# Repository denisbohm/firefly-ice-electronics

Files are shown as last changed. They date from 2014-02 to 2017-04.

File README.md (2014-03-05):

firefly-ice-electronics
=======================

Firefly Ice Activity Monitor / Internet of Things Electronics

See http://fireflydesign.com for information on the open source Firefly Activity Monitor.

Copyright and License 
---------------------
Copyright 2013-2014 Firefly Design LLC / Denis Bohm

<br />This work is licensed under a <a rel="license" href="http://creativecommons.org/licenses/by/3.0/deed.en_US">Creative Commons Attribution 3.0 Unported License</a>.

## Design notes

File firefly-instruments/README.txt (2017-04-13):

Contact: Denis Bohm
denis@fireflydesign.com
(650) 814-1714

April 13h, 2017
Customer: Firefly Design, LLC
Board: Firefly Instrument Tray rev 0.5
Number of Layers: 2
Dimensions: 193 mm x 100 mm
PCB Thickness: 1.60 mm
ENIG
RoHS Compliant
Lead Free Processing

Files

firefly-instrument-tray.sch - Eagle 7 schematic file
firefly-instrument-tray.brd - Eagle 7 board file

firefly-instrument-tray-bom.xlsx - bill of materials
firefly-instrument-tray-schematic.pdf - schematic
firefly-instrument-tray-top-diagram.pdf - top (component) side assembly diagram
firefly-instrument-tray-centroid.csv - surface mount centroid placement data

Gerbers
firefly-instrument-tray.top - top (component) side
firefly-instrument-tray.bot - bottom side

firefly-instrument-tray.slk - top (component) side silk
firefly-instrument-tray.smt - top (component) side solder mask
firefly-instrument-tray.tsp - top (component) side stencil

firefly-instrument-tray.bsk - bottom side silk
firefly-instrument-tray.smb - bottom side solder mask
firefly-instrument-tray.bsp - bottom side stencil

firefly-instrument-tray.oln - outline

firefly-instrument-tray.drd - Excellon drill
firefly-instrument-tray.dri - tool list

Notes:
1) The design is done with Eagle 7.7.0 (files are of type sch, brd, and lib)..
2) Use Firefly Design BOM tool to generate the BOM from the schematic.
3) The tDocu & Document layers show all reference designators and orientation for assembly of the top side.
4) The bDocu shows all reference designators and orientation for assembly of the bottom side.
5) DRC rules and CAM setup are from Sunstone Circuits.  For CAM setup use _tsilk for top side silk and _bsilk for bottom side silk.
6) Centroid file generator is from Screaming Circuits.

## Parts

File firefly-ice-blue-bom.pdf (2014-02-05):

Item # Qty Ref Des | Manufacturer | Mfg Part # | Distributor | Description | Package | Type | DNS | NS
1 | 1 A1 | Fractus | FR05_S1_N_0_110 | RichardsonRFPD | FR05_S1_N_0_110 smt | FALSE FALSE
2 17 C1-2 C9 C12-13 C16-17 C23 C26-31 C41 C43 C55 Murata | GRM033R60J104KE19D | Digikey | 100nF | C0201 | fine pitch FALSE FALSE
3 12 C3 C8 C10-11 C14 C20-21 C24 C36 C42 C50 C52 TDK Corporation | C0603X5R0J105M030BC | Digikey | 1uF | C0201 | fine pitch FALSE FALSE
4 | 3 C4-5 C15 | TDK Corporation | C1005X5R0J475M050BC | Digikey | 4.7uF | C0402 | smt | FALSE FALSE
5 | 2 C6 C46 | TDK | C0603C0G1E1R2B030BF | Digikey | 1.2pF | C0201 | fine pitch FALSE FALSE
6 | 2 C18 C25 | Samsung Electro-Mechanics America, Inc CL05A106MP5NUNC | Digikey | 10uF | C0402 | smt | FALSE FALSE
7 | 1 C19 | TDK Corporation | C1608X5R0J226M080AC | Digikey | 22uF | C0603 | smt | FALSE FALSE
8 | 2 C22 C48 | Johanson Technology Inc | 250R05L180GV4T | Digikey | 18pF | C0201 | fine pitch FALSE FALSE
9 | 2 C32-33 | AVX Corporation | 02013A220GAT2A | Digikey | 22pF | C0201 | fine pitch FALSE FALSE
10 | 2 C34-35 | Johanson Technology Inc | 250R05L150GV4T | Digikey | 15pF | C0201 | fine pitch FALSE FALSE
11 | 1 C39 | Murata | C0603X7R1E102K030BA | Digikey | 1nF | C0201 | fine pitch FALSE FALSE
12 | 1 C40 | Murata | GRM033R60J333KE01D | Digikey | 33nF | C0201 | fine pitch FALSE FALSE
13 | 1 C44 | TDK | C0603X5R1E222K030BA | Digikey | 2.2nF | C0201 | fine pitch FALSE FALSE
14 | 1 C47 | TDK | C0603C0G1E1R8C030BF | Digikey | 1.8pF | C0201 | fine pitch FALSE FALSE
15 | 1 C51 | Kemet | C1206C107M9PACTU | Digikey | 100uF | C1206 | smt | FALSE FALSE
16 | 2 C53-54 | TDK Corporation | C0603X5R0J474M030BC | Digikey | 470nF | C0201 | fine pitch FALSE FALSE
17 | 2 D0 D4 | Rohm Semiconductor | SML-P11UTT86 | Digikey | LEDD0402 | D0402 | smt | FALSE FALSE
18 | 3 D1-3 | Rohm Semiconductor | SMLP36RGB2W3 | Digikey | SMLP36 | smt | FALSE FALSE
19 | 1 D5 | Panasonic Electronic Components | LNJ847W83RA | Digikey | LEDD0402 | D0402 | smt | FALSE FALSE
20 | 1 D6 | Panasonic Electronic Components | LNJ347W83RA | Digikey | LEDD0402 | D0402 | smt | FALSE FALSE
21 | 1 D10 | Rohm Semiconductor | RB161M-20TR | Digikey | BAT54WSSOD-123F | SOD-123F | smt | FALSE FALSE
22 | 1 J1 | Hirose Electric Co Ltd | ZX62WD1-B-5PC | Digikey | USB-5PINZX62WD1-B-5PC ZX62WD1-B-5PC | smt | FALSE FALSE
23 | 1 J2 | Harwin Inc | M40-3100345R | Digikey | CON-6SOCKET | M40-3100345R | smt | FALSE FALSE
24 | 1 L1 | TDK | MLG0603P8N2J | Digikey | 8.2nH | L0201 | fine pitch FALSE FALSE
25 | 1 L2 | TDK | MLG0603P5N6S | Digikey | 5.6nH | L0201 | fine pitch FALSE FALSE
26 | 1 L3 | TDK | MLG0603S3N9S | Digikey | 3.9nH | L0201 | fine pitch FALSE FALSE
27 | 2 L4 L9 | TDK Corporation | MPZ0603S220C | Digikey | Ferrite Bead | L0201 | fine pitch FALSE FALSE
28 | 1 L6 | Taiyo Yuden | HKQ0603S7N5H-T | Digikey | 7.5nH | L0201 | fine pitch FALSE FALSE
29 | 1 L7 | WURTH | 74479775210 | Digikey | 1uH | L0805 | smt | FALSE FALSE
30 | 2 R1 R9 | Panasonic Electronic Components | ERJ-1GEF4701C | Digikey | 4.7k | R0201 | smt | FALSE FALSE
31 | 6 R2 R7 R15 R31-33 | Yageo | RC0201FR-07100KL | Digikey | 100k | R0201 | smt | FALSE FALSE
32 | 1 R3 | Panasonic Electronic Components | ERJ-1GEF1503C | Digikey | 152.4k | R0201 | smt | FALSE FALSE
33 | 1 R4 | Panasonic Electronic Components | ERJ-1GEJ105C | Digikey | 1M | R0201 | smt | FALSE FALSE
34 | 2 R5 R14 | Panasonic Electronic Components | ERJ-1GE0R00C | Digikey | 0 (OPT) (do not stuff) | R0201 | smt | TRUE | FALSE
35 | 1 R6 | Panasonic Electronic Components | ERJ-1GEF24R9C | Digikey | 25 | R0201 | smt | FALSE FALSE
36 | 1 R8 | Panasonic Electronic Components | ERJ-1GEF1242C | Digikey | 12.4k | R0201 | smt | FALSE FALSE
37 | 1 R10 | Panasonic Electronic Components | ERJ-1GEF3922C | Digikey | 39.2k | R0201 | smt | FALSE FALSE
38 | 1 R11 | Panasonic | ERJ-1GEF2202C | Digikey | 22k | R0201 | smt | FALSE FALSE
39 | 1 R12 | Yageo | RC0201FR-07100KL | Digikey | 100k (do not stuff) | R0201 | smt | TRUE | FALSE
40 | 3 R17 R20 R23 | Panasonic Electronic Components | ERJ-1GEF51R0C | Digikey | 50 | R0201 | smt | FALSE FALSE
41 | 1 R25 | Panasonic Electronic Components | ERJ-1GE0R00C | Digikey | 0 | R0201 | smt | FALSE FALSE
42 | 2 R27-28 | Panasonic Electronic Components | ERJ-1GEF15R0C | Digikey | 15 | R0201 | smt | FALSE FALSE
43 | 1 U1 | Energy Micro | EFM32LG330F256 | Digikey | QFN64 | fine pitch FALSE FALSE
44 | 1 U2 | Nordic Semiconductor | nRF8001-R2Q32-T | Mouser | QFN-32 | fine pitch FALSE FALSE
45 | 1 U3 | ST | LIS3DHTR | Digikey | LGA16_3X3 | fine pitch FALSE FALSE
46 | 1 U4 | Freescale Semiconductor | MAG3110FCR1 | Digikey | DFN10-2X2 | fine pitch FALSE FALSE
47 | 1 U5 | Texas Instruments | LP5523TMX/NOPB | Digikey | WL-CSP-25 | fine pitch FALSE FALSE
48 | 1 U6 | Diodes Inc | DMC2990UDJ-7 | Digikey | SOT963 | fine pitch FALSE FALSE
49 | 1 U7 | Microchip | MCP73832-2ACI/MC | Mouser | DFN8 | fine pitch FALSE FALSE
50 | 1 U8 | NXP Semiconductors | IP4059CX5/LF,135 | Digikey | WLCSP5 | fine pitch FALSE FALSE
51 | 1 U9 | Fairchild Semiconductor | FPF1005 | Digikey | MICROFET-2X2-6L smt | FALSE FALSE
52 | 1 U10 | STMicroelectronics | STM6519AHARUB6F | Digikey | UDFN6 | fine pitch FALSE FALSE
53 | 1 U11 | Texas Instruments | TPS78222DRVR | Digikey | S-PWSON-N6 | smt | FALSE FALSE
54 | 1 U12 | Texas Instruments | TPS62080ADSGT | Mouser | S-PWSON-N8 | fine pitch FALSE FALSE
55 | 1 U13 | NXP Semiconductor | NX3L1T53GM,125 | Digikey | SOT902-2 | fine pitch FALSE FALSE
56 | 1 U14 | Fairchild Semiconductor | FDFMA2P857 | Digikey | (do not stuff) | MO-229 | smt | TRUE | FALSE
57 | 1 U16 | Winbond | W25Q16DWBYIG | Arrow | WLBGA-8 | fine pitch FALSE FALSE
58 | 1 U17 | Analog Devices | ADP151ACBZ-1.8-R7 | Digikey | CB-4-3 | fine pitch FALSE FALSE
59 | 1 U18 | NXP Semiconductors | NTB0104GU12,115 | Digikey | XQFN12 | fine pitch FALSE FALSE
60 | 1 X1 | AVX Corp/Kyocera Corp | ST3215SB32768B0HPWB3 Digikey | 32kHz | 9HT10 | smt | FALSE FALSE
61 | 1 X2 | TXC CORPORATION | 7V-16.000MAAE-T | Digikey | 16MHz | XTAL2520 | smt | FALSE FALSE
62 | 1 X4 | Abracon Corporation | ABM11-48.000MHZ-D2X-T3 Digikey | 48MHz | ABM11 | smt | FALSE FALSE

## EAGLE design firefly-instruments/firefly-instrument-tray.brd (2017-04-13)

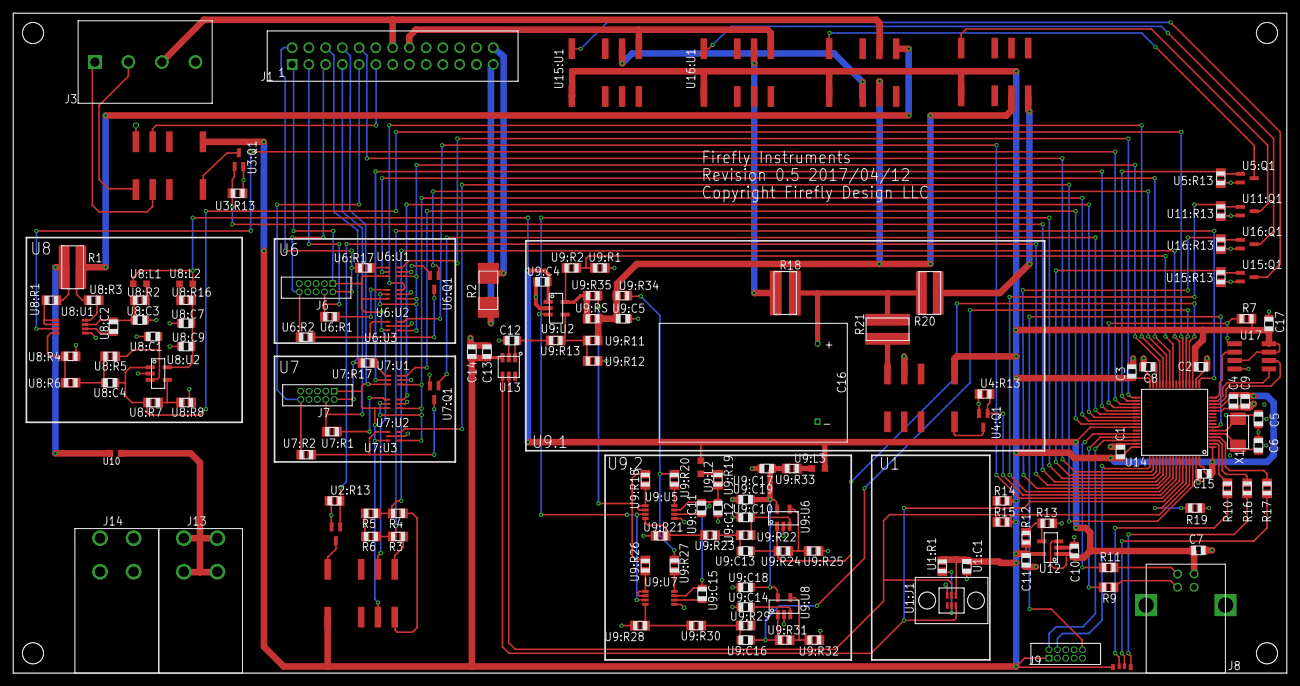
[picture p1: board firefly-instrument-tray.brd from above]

Board: 2 copper layers, 193.0 x 100.0 mm, 153 parts (0 on the bottom side), 129 nets.

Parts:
C1, C2, C3, C12, C13, C15, C17: 100nF; C0805
C4, C10, C11: 1uF; C0805
C5, C6: 22pF; C0805
C7, C8: 4.7uF; C0805
C9: 10nF; C0805
C14: 10uF; C0805
C16: 1F; PM118
D1: LED-RGB-CAMSL0201RGB; MSL0201RGB
J1: CON-26; CON-HEADER-2X13
J3: CON-4282847-4; 282847-4
J6, J7, J9: CON-10SWD; SWD-10
J8: USB-4PINUSB-B1HSB6; USB-B1HSB6
J13, J14: CON-1CT3151; CT3151
R1: 0.1; KRL6432
R2: 100; RW0S6BB
R3, R4, R5, R6: 1k; R0805
R7: 10k; R0805
R9, R11: 22; R0805
R10, R16: 60; R0805
R12: 72.5k; R0805
R13: 10K; R0805
R14, R15: 4.7k; R0805
R17: 240; R0805
R18: 1 (2W WW); RCL1225
R19: 0; R0805
R20: 49.9 (2W WW); KRL6432
R21: 49.9 (2W WW); RCL1225
U1:C1, U8:C7, U9:C4, U9:C5, U9:C17: 1uF; C0805
U1:J1: SMFLP
U1:R1, U8:R5, U8:R6, U9:R22, U9:R23, U9:R29, U9:R30: 10k; R0805
U1:U1: TCS3471; DFN6
U2:Q1, U3:Q1, U4:Q1, U5:Q1, U6:Q1, U7:Q1, U11:Q1, U15:Q1, U16:Q1: FET-NMCPH3; MCPH3
U2:R13, U3:R13, U4:R13, U5:R13, U9:R28, U11:R13, U15:R13, U16:R13: 10K; R0805
U2:U1, U3:U1, U4:U1, U5:U1, U11:U1, U15:U1, U16:U1: TXS2SA
U6:R1, U6:R2, U6:R17, U7:R1, U7:R2, U7:R17: 240; R0805
U6:U1, U6:U2, U6:U3, U7:U1, U7:U2, U7:U3: 74LVCH1T45; SOT363
U8:C1, U8:C4, U9:C10, U9:C13, U9:C14, U9:C16: 1nF; C0805
U8:C2, U8:C9, U9:C11, U9:C15, U9:C18, U9:C19: 100nF; C0805
U8:C3, U9:C12: 10uF; C0805
U8:L1, U8:L2, U9:L2, U9:L3: 1k; L2012C
U8:R1, U9:R18: 1.8K; R0805
U8:R2, U9:R19, U9:R27, U9:R31, U9:R34, U9:R35: 0; R0805
U8:R3, U9:R20: 43; R0805
U8:R4, U9:R21: 12K; R0805
U8:R7, U9:R24: 376; R0805
U8:R8, U9:R25, U9:R32: 1K; R0805
U8:R16, U9:R33: 1; R0805
U8:U1, U9:U5, U9:U7: LTC6102-1MS8; MSOP8
U8:U2, U9:U6, U9:U8: TLV271SN2T1G; SOT-23-5
U9:R1, U9:R2, U9:R12, U9:R13: 100K; R0805
U9:R11: 650K; R0805
U9:R26, U9:RS: 4.7; R0805
U9:U2, U12: VREG-ADJAP7331-WG-7; SOT-23-5
U10: PTC0603; 0603
U13: MCP47X6; SOT-23-6
U14: STM32F411-LQFP64; LQFP-64
U17: MEMORY-SPISOA008; SOA008
X1: XTAL2CX5032GA; CX5032GA

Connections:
+3V3: C1.1, C2.1, C3.1, C4.1, C9.1, C11.1, C13.1, C14.1, C15.1, C17.1, D1.4, J9.1, R7.2, R12.2, R14.2, R15.2, U1:C1.1, U1:R1.2, U1:U1.1, U2:U1.1, U3:U1.1, U4:U1.1, U5:U1.1, U11:U1.1, U12.5, U13.3, U14.1, U14.13, U14.19, U14.32, U14.48, U14.64, U15:U1.1, U16:U1.1, U17.3, U17.7, U17.8
+5V: J13.1, J13.2, J13.3, J13.4, U10.1
ATE_BATTERY+2: U9:R1.2, U9:R2.1, U14.25
ATE_BAT_ADJ_EN: U14.51, U15:Q1.1, U15:R13.2
ATE_BAT_CAP_EN: U14.55, U16:Q1.1, U16:R13.2
ATE_BS_ADJ: C12.1, U9:R13.1, U13.1
ATE_BS_EN: U9:U2.3, U9:U5.3, U9:U7.3, U14.52
ATE_BS_SHR: U9:C13.1, U9:R24.2, U9:U6.1, U14.20
ATE_BS_SLR: U9:C16.1, U9:R31.2, U9:U8.1, U14.21
ATE_BUTTON_EN: U3:Q1.1, U3:R13.2, U14.53
ATE_DRAIN_EN: U4:Q1.1, U4:R13.2, U14.57
ATE_FILL_EN: U11:Q1.1, U11:R13.2, U14.56
ATE_MCU1_VCC2: R3.2, R6.1, U14.17
ATE_MCU2_VCC2: R4.2, R5.1, U14.23
ATE_MCU_VCC_SENSE: U2:Q1.1, U2:R13.2, U14.54
ATE_SCL: R15.1, U1:U1.2, U13.5, U14.61
ATE_SDA: R14.1, U1:U1.6, U13.4, U14.59
ATE_SWD1_DIR_TO_DUT: U6:U1.5, U14.26
ATE_SWD1_NRESET: U6:Q1.1, U14.27
ATE_SWD1_PWR: U6:U1.1, U6:U2.1, U6:U2.5, U6:U3.1, U14.29
ATE_SWD1_SENSE_NRESET: U6:U3.3, U14.58
ATE_SWD1_SWDCLK: U6:U2.3, U14.28
ATE_SWD1_SWDIO: U6:U1.3, U14.33
ATE_SWD2_DIR_TO_DUT: U7:U1.5, U14.37
ATE_SWD2_NRESET: U7:Q1.1, U14.38
ATE_SWD2_PWR: U7:U1.1, U7:U2.1, U7:U2.5, U7:U3.1, U14.40
ATE_SWD2_SENSE_NRESET: U7:U3.3, U14.62
ATE_SWD2_SWDCLK: U7:U2.3, U14.39
ATE_SWD2_SWDIO: U7:U1.3, U14.41
ATE_USB_5V_EN: U5:Q1.1, U5:R13.2, U14.34
ATE_USB_CS_EN: U8:U1.3, U14.35
ATE_USB_CS_OUT: U8:C4.1, U8:R7.2, U8:U2.1, U14.22
BATADJ: U5:U1.4, U9:C5.1, U9:R11.2, U9:R34.2, U9:RS.2, U11:U1.4
BATADJSAFE: U5:U1.3, U15:U1.9
BATCAP: R18.1, U16:U1.9
BOOT0: R19.1, U14.60
DRAINCAP: R21.1, U4:U1.5
DUT_BATTERY+: J1.16, U15:U1.8, U16:U1.8
DUT_BUTTON+: J1.11, U3:U1.4
DUT_MCU1_NRESET: J1.5, J6.10, U6:R2.2
DUT_MCU1_SWDCLK: J1.3, J6.4, U6:R1.2
DUT_MCU1_SWDIO: J1.2, J6.2, U6:R17.2
DUT_MCU1_VCC: J1.1, J6.1, U2:U1.9, U6:U1.6, U6:U2.6, U6:U3.6
DUT_MCU2_BOOT0: J1.10, U14.50
DUT_MCU2_NRESET: J1.9, J7.10, U7:R2.2
DUT_MCU2_SWDCLK: J1.7, J7.4, U7:R1.2
DUT_MCU2_SWDIO: J1.6, J7.2, U7:R17.2
DUT_MCU2_VCC: J1.8, J7.1, U2:U1.4, U7:U1.6, U7:U2.6, U7:U3.6
DUT_MOTOR+: J1.26, R2.1
DUT_MOTOR-: J1.25, R2.2
DUT_SWITCH_1: J3.1, U3:U1.9
DUT_SWITCH_2: J3.2, U3:U1.8
DUT_USB_5V: J1.14, J3.3, U5:U1.9
FILLCAP: R20.1, U11:U1.5
GND: C1.2, C2.2, C3.2, C4.2, C5.2, C6.2, C7.2, C8.2, C9.2, C10.2, C11.2, C12.2, C13.2, C14.2, C15.2, C16.-, C17.2, J1.4, J1.23, J1.24, J3.4, J6.3, J6.5, J7.3, J7.5, J8.4, J9.3, J9.5, J14.1, J14.2, J14.3, J14.4, R5.2, R6.2, R13.1, R19.2, U1:C1.2, U1:U1.3, U2:Q1.2, U2:R13.1, U3:Q1.2, U3:R13.1, U3:U1.5, U4:Q1.2, U4:R13.1, U4:U1.4, U5:Q1.2, U5:R13.1, U6:Q1.2, U6:U1.2, U6:U2.2, U6:U3.2, U6:U3.5, U7:Q1.2, U7:U1.2, U7:U2.2, U7:U3.2, U7:U3.5, U8:C1.2, U8:C3.2, U8:C7.2, U8:C9.2, U8:R4.2, U8:R8.2, U8:U1.5, U8:U2.2, U9:C4.2, U9:C5.2, U9:C10.2, U9:C12.2, U9:C14.2, U9:C17.2, U9:C18.2, U9:C19.2, U9:R1.1, U9:R12.1, U9:R21.2, U9:R25.2, U9:R28.2, U9:R32.2, U9:U2.2, U9:U5.5, U9:U6.2, U9:U7.5, U9:U8.2, U11:Q1.2, U11:R13.1, U12.2, U13.2, U14.12, U14.18, U14.31, U14.47, U14.63, U15:Q1.2, U15:R13.1, U16:Q1.2, U16:R13.1, U17.4
MEM_CSN: R7.1, U14.36, U17.1
unnamed: R10.2, U14.2
unnamed: R1.2, U5:U1.8, U8:R3.1
unnamed: R1.1, U8:R1.2, U10.2
unnamed: C16.+, R18.2, R20.2, R21.2
unnamed: C5.1, U14.6, X1.2
unnamed: C6.1, U14.5, X1.1
unnamed: R16.2, U14.3
unnamed: R4.1, U2:U1.5
unnamed: R3.1, U2:U1.8
unnamed: C8.1, U14.30
unnamed: R12.1, R13.2, U12.4
unnamed: J8.2, R11.2
unnamed: R17.2, U14.4
unnamed: J8.3, R9.2
unnamed: D1.3, R10.1
unnamed: D1.1, R16.1
unnamed: D1.2, R17.1
NRESET: J9.10, U14.7
SPI_MISO: U14.16, U17.2
SPI_MOSI: U14.15, U17.5
SPI_SCLK: U14.14, U17.6
SWCLK: J9.4, U14.49
SWDIO: J9.2, U14.46
U1:INT: U1:R1.1, U1:U1.5
U2:N$2: U2:Q1.3, U2:U1.12
U3:N$2: U3:Q1.3, U3:U1.12
U4:N$2: U4:Q1.3, U4:U1.12
U5:N$2: U5:Q1.3, U5:U1.12
U6:N$1: U6:Q1.3, U6:R2.1, U6:U3.4
U6:N$2: U6:R17.1, U6:U1.4
U6:N$3: U6:R1.1, U6:U2.4
U7:N$1: U7:Q1.3, U7:R2.1, U7:U3.4
U7:N$2: U7:R17.1, U7:U1.4
U7:N$3: U7:R1.1, U7:U2.4
U8:N$1: U8:L1.2, U8:R2.2
U8:N$2: U8:L2.2, U8:R16.2
U8:N$3: U8:C2.1, U8:U1.6
U8:N$4: U8:R1.1, U8:U1.1, U8:U1.2
U8:N$7: U8:R3.2, U8:U1.8
U8:N$9: U8:R4.1, U8:R6.1, U8:U1.4
U8:N$10: U8:C4.2, U8:R5.1, U8:R6.2
U8:N$11: U8:C1.1, U8:R5.2, U8:U2.3
U8:N$12: U8:R7.1, U8:R8.1, U8:U2.4
U8:VCSA: U8:C2.2, U8:C3.1, U8:R2.1, U8:U1.7
U8:VOA: U8:C7.1, U8:C9.1, U8:R16.1, U8:U2.5
U9:N$4: U9:R11.1, U9:R12.2, U9:R13.2, U9:U2.4
U9:N$13: U9:L2.2, U9:R19.2
U9:N$14: U9:C11.1, U9:U5.6
U9:N$15: U9:R18.1, U9:U5.1, U9:U5.2
U9:N$16: U9:R20.2, U9:U5.8
U9:N$17: U9:R21.1, U9:R23.1, U9:U5.4
U9:N$18: U9:C13.2, U9:R22.1, U9:R23.2
U9:N$19: U9:C10.1, U9:R22.2, U9:U6.3
U9:N$20: U9:R24.1, U9:R25.1, U9:U6.4
U9:N$21: U9:C15.1, U9:U7.6
U9:N$22: U9:R26.1, U9:U7.1, U9:U7.2
U9:N$23: U9:R27.2, U9:U7.8
U9:N$24: U9:R28.1, U9:R30.1, U9:U7.4
U9:N$25: U9:C16.2, U9:R29.1, U9:R30.2
U9:N$26: U9:C14.1, U9:R29.2, U9:U8.3
U9:N$27: U9:R31.1, U9:R32.1, U9:U8.4
U9:N$28: U9:L3.2, U9:R33.2
U9:N$35: U9:R2.2, U9:R35.2, U9:RS.1, U9:U2.5
U9:SENSE_R: U9:R18.2, U9:R26.2, U9:R35.1
U9:SENSE_S: U9:R20.1, U9:R27.1, U9:R34.1
U9:VCSA: U9:C11.2, U9:C12.1, U9:C15.2, U9:R19.1, U9:U5.7, U9:U7.7
U9:VOA: U9:C17.1, U9:C18.1, U9:C19.1, U9:R33.1, U9:U6.5, U9:U8.5
U11:N$2: U11:Q1.3, U11:U1.12
U15:N$2: U15:Q1.3, U15:U1.12
U16:N$2: U16:Q1.3, U16:U1.12
USB_DM: R11.1, U14.44
USB_DP: R9.1, U14.45
USB_VBUS: C7.1, C10.1, J8.1, U8:L1.1, U8:L2.1, U9:C4.1, U9:L2.1, U9:L3.1, U9:U2.1, U12.1, U12.3, U14.42

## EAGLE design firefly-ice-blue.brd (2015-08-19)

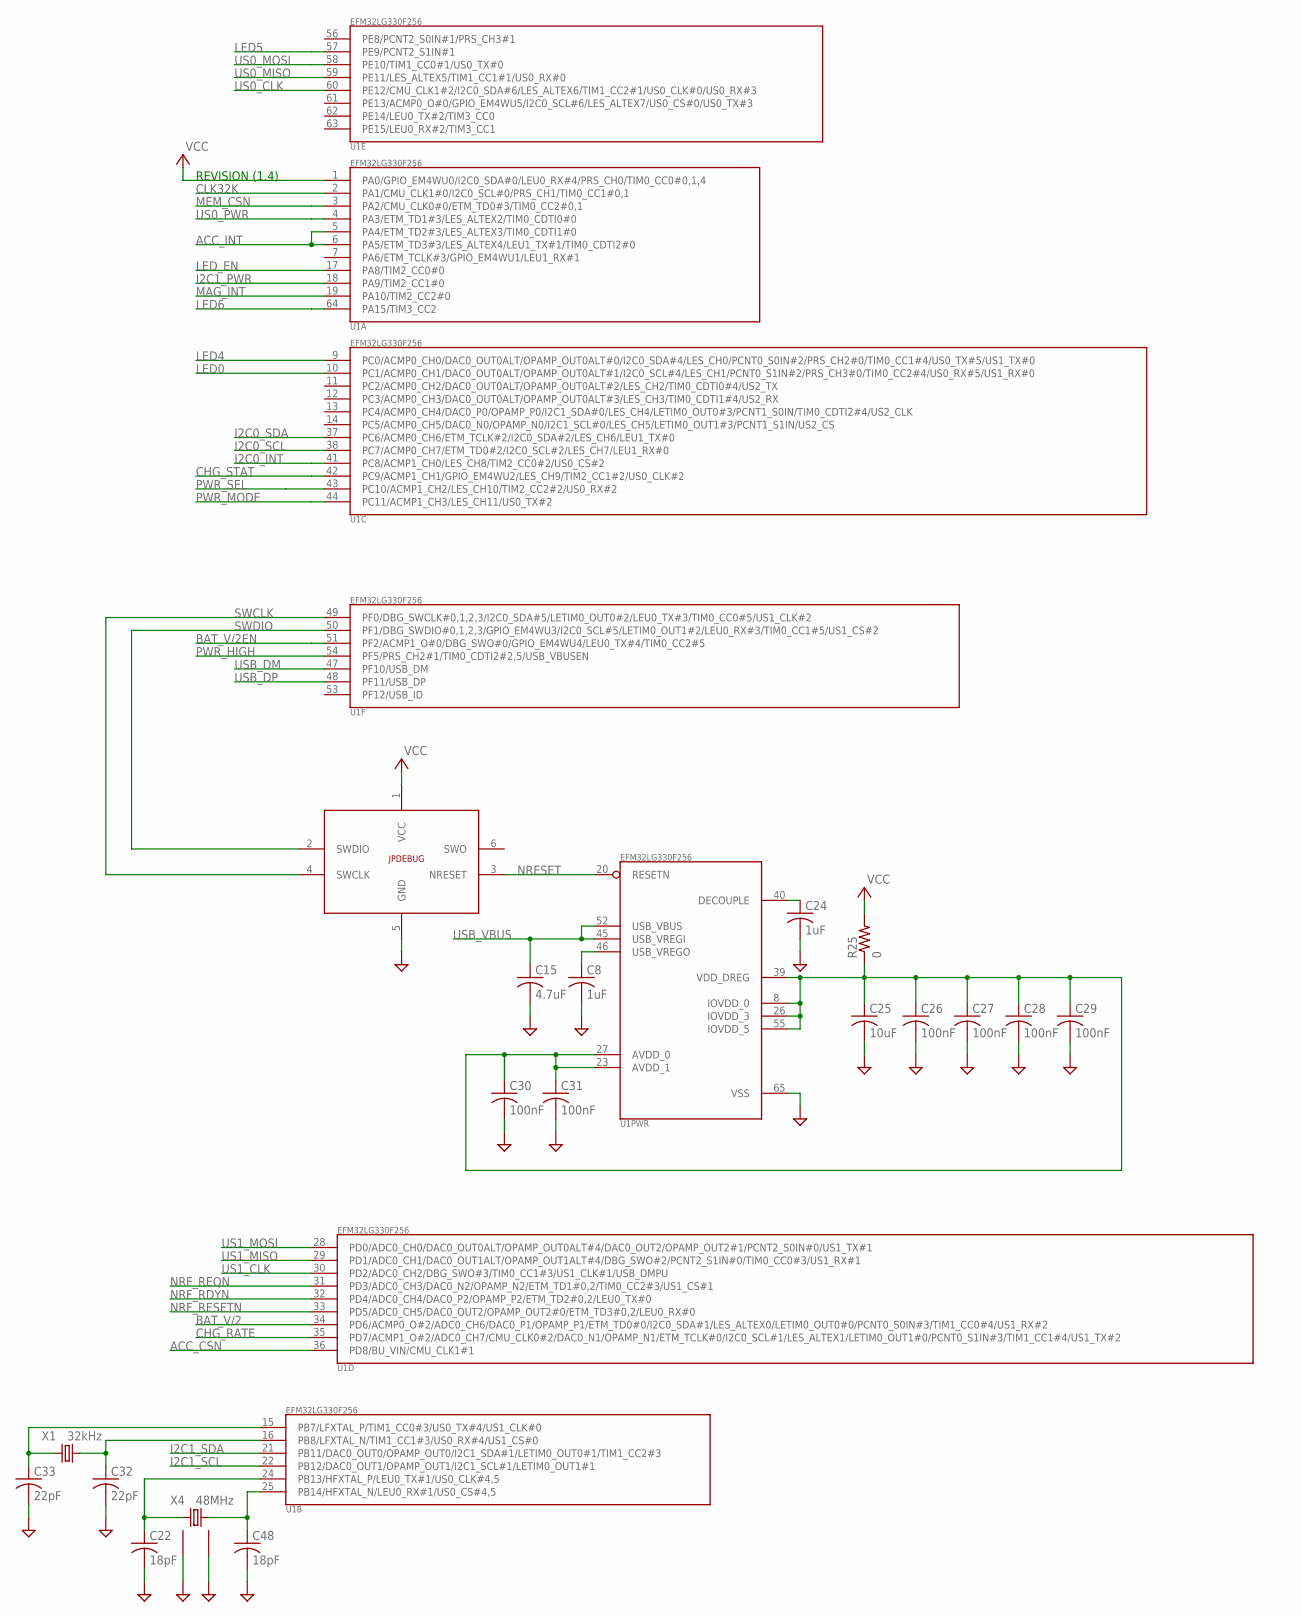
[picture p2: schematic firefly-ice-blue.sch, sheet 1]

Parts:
C8, C24: 1uF; C0201
C15: 4.7uF; C0402
C22, C48: 18pF; C0201
C25: 10uF; C0402
C26, C27, C28, C29, C30, C31: 100nF; C0201
C32, C33: 22pF; C0201
JPDEBUG: TC2030-SWD; TC2030-MCP-NL
R25: 0; R0201
U1: EFM32LG330F256; QFN64
X1: 32kHz; 9HT10
X4: 48MHz; ABM11

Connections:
ACC_CSN: U1.36 (PD8/BU_VIN/CMU_CLK1#1); also elsewhere on the board
ACC_INT: U1.5 (PA4/ETM_TD2#3/LES_ALTEX3/TIM0_CDTI1#0), U1.6 (PA5/ETM_TD3#3/LES_ALTEX4/LEU1_TX#1/TIM0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); also elsewhere on the board
BAT_V/2: U1.34 (PD6/ACMP0_O#2/ADC0_CH6/DAC0_P1/OPAMP_P1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); also elsewhere on the board
BAT_V/2EN: U1.51 (PF2/ACMP1_O#0/DBG_SWO#0/GPIO_EM4WU4/LEU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); also elsewhere on the board
CHG_RATE: U1.35 (PD7/ACMP1_O#2/ADC0_CH7/CMU_CLK0#2/DAC0_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); also elsewhere on the board
CHG_STAT: U1.42 (PC9/ACMP1_CH1/GPIO_EM4WU2/LES_CH9/TIM2_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); also elsewhere on the board
CLK32K: U1.2 (PA1/CMU_CLK1#0/I2C0_SCL#0/PRS_CH1/TIM0_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); also elsewhere on the board
GND: C8.2, C15.2, C22.2, C24.2, C25.2, C26.2, C27.2, C28.2, C29.2, C30.2, C31.2, C32.2, C33.2, C48.2, JPDEBUG.5 (GND), U1.65 (VSS), X4.2 (GND1), X4.4 (GND2); also elsewhere on the board
I2C0_INT: U1.41 (PC8/ACMP1_CH0/LES_CH8/TIM2_CC0#2/US0_CS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); also elsewhere on the board
I2C0_SCL: U1.38 (PC7/ACMP0_CH7/ETM_TD0#2/I2C0_SCL#2/LES_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); also elsewhere on the board
I2C0_SDA: U1.37 (PC6/ACMP0_CH6/ETM_TCLK#2/I2C0_SDA#2/LES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); also elsewhere on the board
I2C1_PWR: U1.18 (PA9/TIM2_CC1#0); also elsewhere on the board
I2C1_SCL: U1.22 (PB12/DAC0_OUT1/OPAMP_OUT1/I2C1_SCL#1/LE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); also elsewhere on the board
I2C1_SDA: U1.21 (PB11/DAC0_OUT0/OPAMP_OUT0/I2C1_SDA#1/LE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); also elsewhere on the board
LED0: U1.10 (PC1/ACMP0_CH1/DAC0_OUT0ALT/OPAMP_OUT0AL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); also elsewhere on the board
LED4: U1.9 (PC0/ACMP0_CH0/DAC0_OUT0ALT/OPAMP_OUT0AL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); also elsewhere on the board
LED5: U1.57 (PE9/PCNT2_S1IN#1); also elsewhere on the board
LED6: U1.64 (PA15/TIM3_CC2); also elsewhere on the board
LED_EN: U1.17 (PA8/TIM2_CC0#0); also elsewhere on the board
MAG_INT: U1.19 (PA10/TIM2_CC2#0); also elsewhere on the board
MEM_CSN: U1.3 (PA2/CMU_CLK0#0/ETM_TD0#3/TIM0_CC2#0,1); also elsewhere on the board
unnamed: C8.1, U1.46 (USB_VREGO)
unnamed: C48.1, U1.25 (PB14/HFXTAL_N/LEU0_RX#1/US0_CS#4,5), X4.3 (2)
unnamed: C24.1, U1.40 (DECOUPLE)
unnamed: C33.1, U1.15 (PB7/LFXTAL_P/TIM1_CC0#3/US0_TX#4/US1_CL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), X1.1
unnamed: C22.1, U1.24 (PB13/HFXTAL_P/LEU0_TX#1/US0_CLK#4,5), X4.1
unnamed: C32.1, U1.16 (PB8/LFXTAL_N/TIM1_CC1#3/US0_RX#4/US1_CS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), X1.2
unnamed: C25.1, C26.1, C27.1, C28.1, C29.1, C30.1, C31.1, R25.1, U1.8 (IOVDD_0), U1.23 (AVDD_1), U1.26 (IOVDD_3), U1.27 (AVDD_0), U1.39 (VDD_DREG), U1.55 (IOVDD_5)
NRESET: JPDEBUG.3 (NRESET), U1.20 (RESETN); also elsewhere on the board
NRF_RDYN: U1.32 (PD4/ADC0_CH4/DAC0_P2/OPAMP_P2/ETM_TD2#0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); also elsewhere on the board
NRF_REQN: U1.31 (PD3/ADC0_CH3/DAC0_N2/OPAMP_N2/ETM_TD1#0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); also elsewhere on the board
NRF_RESETN: U1.33 (PD5/ADC0_CH5/DAC0_OUT2/OPAMP_OUT2#0/ETM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); also elsewhere on the board
PWR_HIGH: U1.54 (PF5/PRS_CH2#1/TIM0_CDTI2#2,5/USB_VBUSEN); also elsewhere on the board
PWR_MODE: U1.44 (PC11/ACMP1_CH3/LES_CH11/US0_TX#2); also elsewhere on the board
PWR_SEL: U1.43 (PC10/ACMP1_CH2/LES_CH10/TIM2_CC2#2/US0_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); also elsewhere on the board
SWCLK: JPDEBUG.4 (SWCLK), U1.49 (PF0/DBG_SWCLK#0,1,2,3/I2C0_SDA#5/LETIM0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)
SWDIO: JPDEBUG.2 (SWDIO), U1.50 (PF1/DBG_SWDIO#0,1,2,3/GPIO_EM4WU3/I2C0_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)
US0_CLK: U1.60 (PE12/CMU_CLK1#2/I2C0_SDA#6/LES_ALTEX6/T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); also elsewhere on the board
US0_MISO: U1.59 (PE11/LES_ALTEX5/TIM1_CC1#1/US0_RX#0); also elsewhere on the board
US0_MOSI: U1.58 (PE10/TIM1_CC0#1/US0_TX#0); also elsewhere on the board
US0_PWR: U1.4 (PA3/ETM_TD1#3/LES_ALTEX2/TIM0_CDTI0#0); also elsewhere on the board
US1_CLK: U1.30 (PD2/ADC0_CH2/DBG_SWO#3/TIM0_CC1#3/US1_C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); also elsewhere on the board
US1_MISO: U1.29 (PD1/ADC0_CH1/DAC0_OUT1ALT/OPAMP_OUT1ALT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); also elsewhere on the board
US1_MOSI: U1.28 (PD0/ADC0_CH0/DAC0_OUT0ALT/OPAMP_OUT0ALT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); also elsewhere on the board
USB_DM: U1.47 (PF10/USB_DM); also elsewhere on the board
USB_DP: U1.48 (PF11/USB_DP); also elsewhere on the board
USB_VBUS: C15.1, U1.45 (USB_VREGI), U1.52 (USB_VBUS); also elsewhere on the board
VCC: JPDEBUG.1 (VCC), R25.2, U1.1 (PA0/GPIO_EM4WU0/I2C0_SDA#0/LEU0_RX#4/PR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); also elsewhere on the board

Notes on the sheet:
REVISION (1.4)

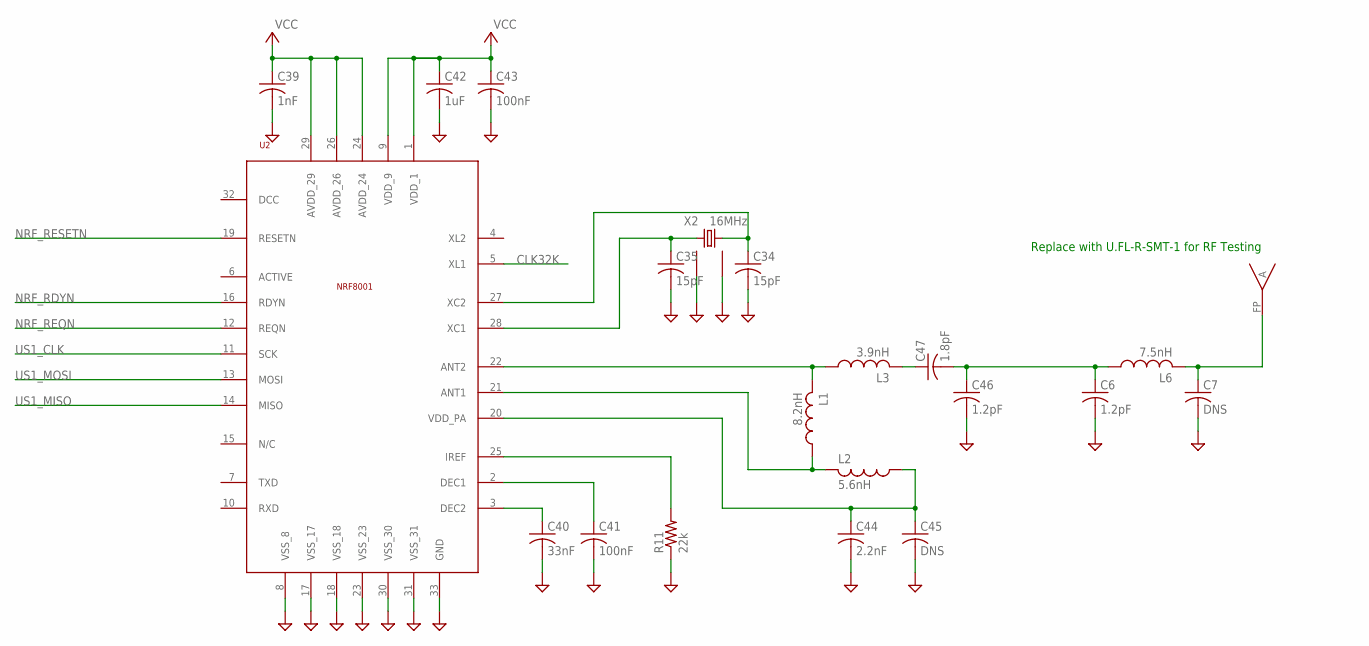
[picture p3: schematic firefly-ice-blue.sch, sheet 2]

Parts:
A1: FR05_S1_N_0_110
C6, C46: 1.2pF; C0201
C7, C45: DNS; C0201
C34, C35: 15pF; C0201
C39: 1nF; C0201
C40: 33nF; C0201
C41, C43: 100nF; C0201
C42: 1uF; C0201
C44: 2.2nF; C0201
C47: 1.8pF; C0201
L1: 8.2nH; L0201
L2: 5.6nH; L0201
L3: 3.9nH; L0201
L6: 7.5nH; L0201
R11: 22k; R0201
U2: NRF8001; QFN-32
X2: 16MHz; XTAL2520

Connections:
CLK32K: U2.5 (XL1); also elsewhere on the board
GND: C6.2, C7.2, C34.2, C35.2, C39.2, C40.2, C41.2, C42.2, C43.2, C44.2, C45.2, C46.2, R11.1, U2.8 (VSS_8), U2.17 (VSS_17), U2.18 (VSS_18), U2.23 (VSS_23), U2.30 (VSS_30), U2.31 (VSS_31), U2.33 (GND), X2.2 (GND1), X2.4 (GND2); also elsewhere on the board
unnamed: A1.FP, C7.1, L6.2
unnamed: C35.1, U2.28 (XC1), X2.1
unnamed: C34.1, U2.27 (XC2), X2.3 (2)
unnamed: R11.2, U2.25 (IREF)
unnamed: C40.1, U2.3 (DEC2)
unnamed: C41.1, U2.2 (DEC1)
unnamed: C47.1, L3.2
unnamed: C6.1, C46.1, C47.2, L6.1
unnamed: C44.1, C45.1, L2.1, U2.20 (VDD_PA)
unnamed: L1.1, L2.2, U2.21 (ANT1)
unnamed: L1.2, L3.1, U2.22 (ANT2)
NRF_RDYN: U2.16 (RDYN); also elsewhere on the board
NRF_REQN: U2.12 (REQN); also elsewhere on the board
NRF_RESETN: U2.19 (RESETN); also elsewhere on the board
US1_CLK: U2.11 (SCK); also elsewhere on the board
US1_MISO: U2.14 (MISO); also elsewhere on the board
US1_MOSI: U2.13 (MOSI); also elsewhere on the board
VCC: C39.1, C42.1, C43.1, U2.1 (VDD_1), U2.9 (VDD_9), U2.24 (AVDD_24), U2.26 (AVDD_26), U2.29 (AVDD_29); also elsewhere on the board

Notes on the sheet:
Replace with U.FL-R-SMT-1 for RF Testing

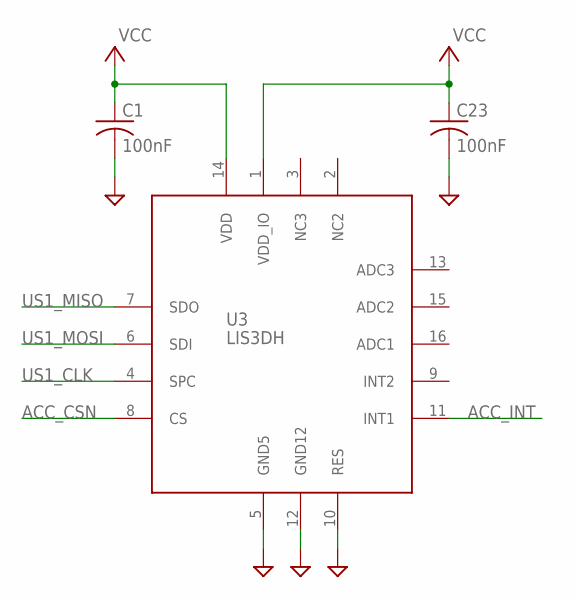
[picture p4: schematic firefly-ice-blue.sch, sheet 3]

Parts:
C1, C23: 100nF; C0201
U3: LIS3DH; LGA16_3X3

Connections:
ACC_CSN: U3.8 (CS); also elsewhere on the board
ACC_INT: U3.11 (INT1); also elsewhere on the board
GND: C1.2, C23.2, U3.5 (GND5), U3.10 (RES), U3.12 (GND12); also elsewhere on the board
US1_CLK: U3.4 (SPC); also elsewhere on the board
US1_MISO: U3.7 (SDO); also elsewhere on the board
US1_MOSI: U3.6 (SDI); also elsewhere on the board
VCC: C1.1, C23.1, U3.1 (VDD_IO), U3.14 (VDD); also elsewhere on the board

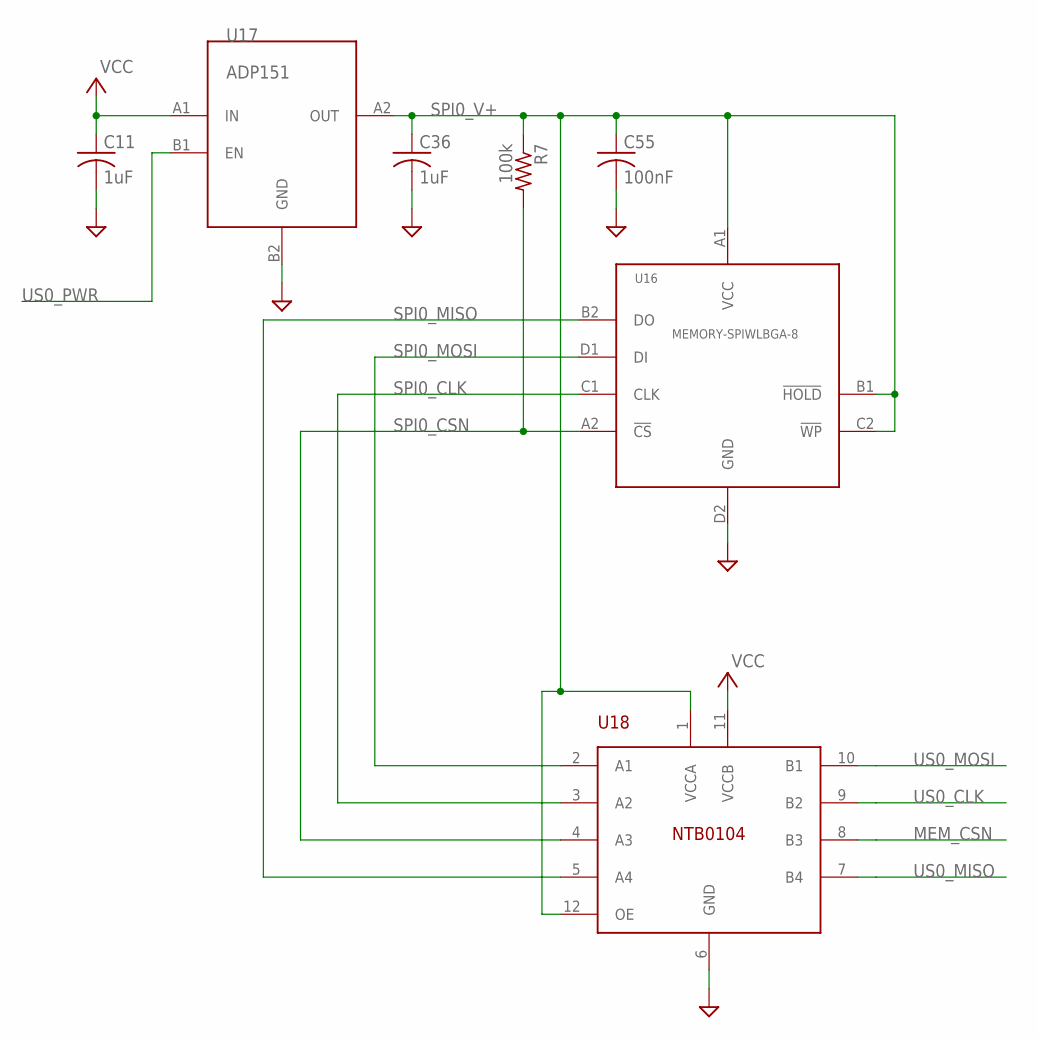
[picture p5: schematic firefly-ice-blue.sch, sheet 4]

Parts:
C11, C36: 1uF; C0201
C55: 100nF; C0201
R7: 100k; R0201
U16: MEMORY-SPIWLBGA-8; WLBGA-8
U17: ADP151; CB-4-3
U18: NTB0104; XQFN12

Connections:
GND: C11.2, C36.2, C55.2, U16.D2 (GND), U17.B2 (GND), U18.6 (GND); also elsewhere on the board
MEM_CSN: U18.8 (B3); also elsewhere on the board
SPI0_CLK: U16.C1 (CLK), U18.3 (A2)
SPI0_CSN: R7.2, U16.A2 (!CS), U18.4 (A3)
SPI0_MISO: U16.B2 (DO), U18.5 (A4)
SPI0_MOSI: U16.D1 (DI), U18.2 (A1)
SPI0_V+: C36.1, C55.1, R7.1, U16.A1 (VCC), U16.B1 (!HOLD), U16.C2 (!WP), U17.A2 (OUT), U18.1 (VCCA), U18.12 (OE)
US0_CLK: U18.9 (B2); also elsewhere on the board
US0_MISO: U18.7 (B4); also elsewhere on the board
US0_MOSI: U18.10 (B1); also elsewhere on the board
US0_PWR: U17.B1 (EN); also elsewhere on the board
VCC: C11.1, U17.A1 (IN), U18.11 (VCCB); also elsewhere on the board

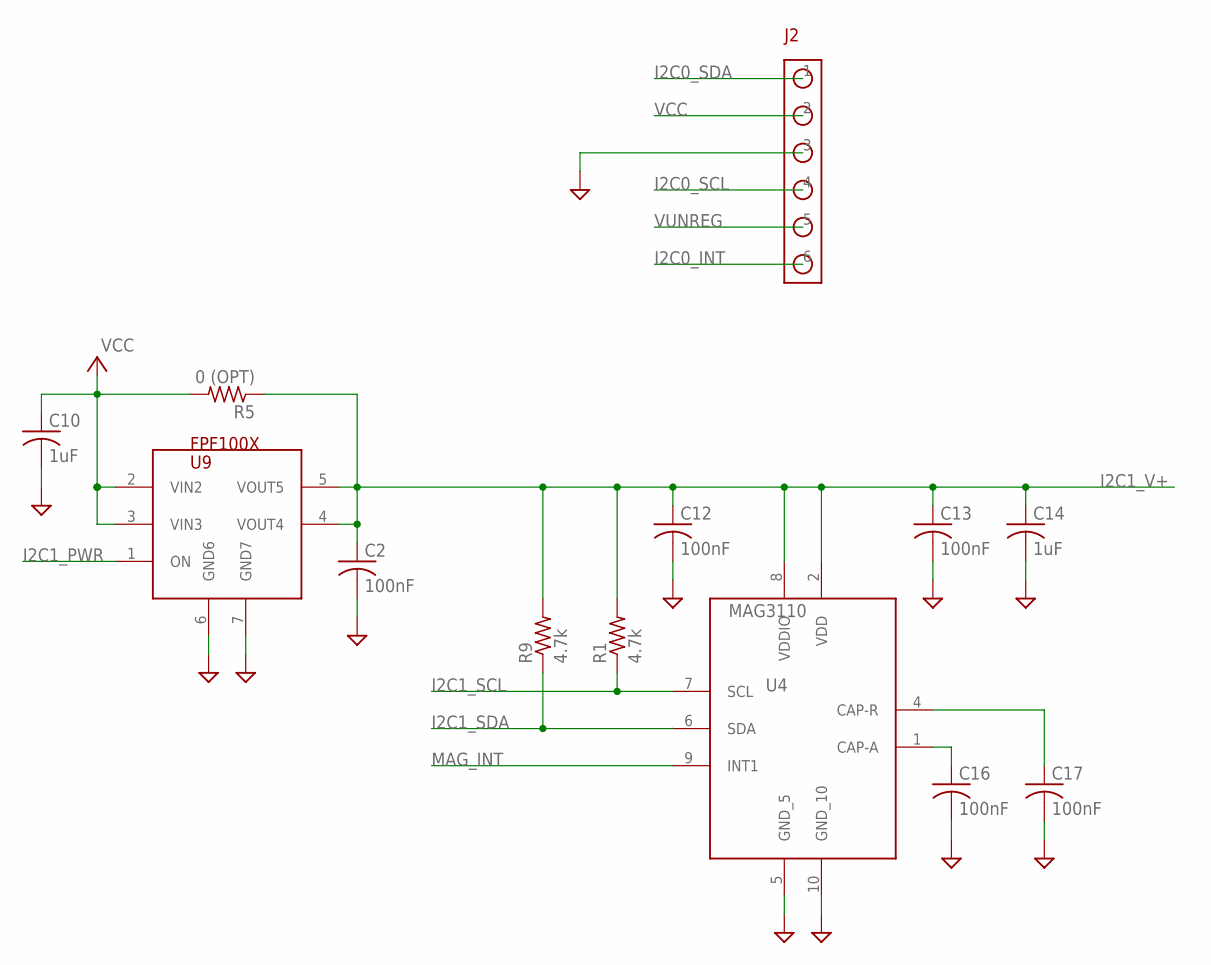
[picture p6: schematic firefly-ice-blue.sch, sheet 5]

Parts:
C2, C12, C13, C16, C17: 100nF; C0201
C10, C14: 1uF; C0201
J2: CON-6SOCKET; M40-3100345R
R1, R9: 4.7k; R0201
R5: 0 (OPT); R0201
U4: MAG3110; DFN10-2X2
U9: FPF100X; MICROFET-2X2-6L

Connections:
GND: C2.2, C10.2, C12.2, C13.2, C14.2, C16.2, C17.2, J2.3, U4.5 (GND_5), U4.10 (GND_10), U9.6 (GND6), U9.7 (GND7); also elsewhere on the board
I2C0_INT: J2.6; also elsewhere on the board
I2C0_SCL: J2.4; also elsewhere on the board
I2C0_SDA: J2.1; also elsewhere on the board
I2C1_PWR: U9.1 (ON); also elsewhere on the board
I2C1_SCL: R1.1, U4.7 (SCL); also elsewhere on the board
I2C1_SDA: R9.1, U4.6 (SDA); also elsewhere on the board
I2C1_V+: C2.1, C12.1, C13.1, C14.1, R1.2, R5.1, R9.2, U4.2 (VDD), U4.8 (VDDIO), U9.4 (VOUT4), U9.5 (VOUT5)
MAG_INT: U4.9 (INT1); also elsewhere on the board
unnamed: C16.1, U4.1 (CAP-A)
unnamed: C17.1, U4.4 (CAP-R)
VCC: C10.1, J2.2, R5.2, U9.2 (VIN2), U9.3 (VIN3); also elsewhere on the board
VUNREG: J2.5; also elsewhere on the board

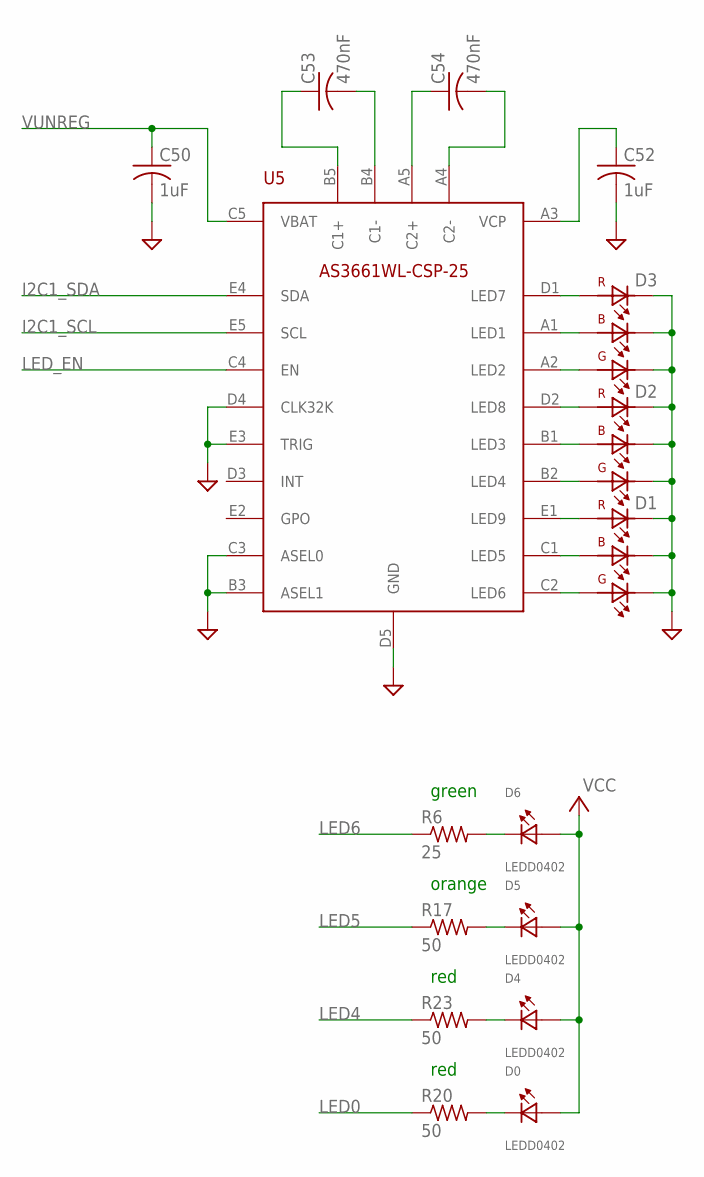
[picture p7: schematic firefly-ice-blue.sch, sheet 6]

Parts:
C50, C52: 1uF; C0201
C53, C54: 470nF; C0201
D0, D4, D5, D6: LEDD0402; D0402
D1, D2, D3: LED-RGB; SMLP36
R6: 25; R0201
R17, R20, R23: 50; R0201
U5: AS3661WL-CSP-25; WL-CSP-25

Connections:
GND: C50.2, C52.2, D1.1 (BC), D1.3 (RC), D1.5 (GC), D2.1 (BC), D2.3 (RC), D2.5 (GC), D3.1 (BC), D3.3 (RC), D3.5 (GC), U5.B3 (ASEL1), U5.C3 (ASEL0), U5.D4 (CLK32K), U5.D5 (GND), U5.E3 (TRIG); also elsewhere on the board
I2C1_SCL: U5.E5 (SCL); also elsewhere on the board
I2C1_SDA: U5.E4 (SDA); also elsewhere on the board
LED0: R20.1; also elsewhere on the board
LED4: R23.1; also elsewhere on the board
LED5: R17.1; also elsewhere on the board
LED6: R6.1; also elsewhere on the board
LED_EN: U5.C4 (EN); also elsewhere on the board
unnamed: D1.2 (BA), U5.C2 (LED6)
unnamed: C52.1, U5.A3 (VCP)
unnamed: C53.2, U5.B4 (C1-)
unnamed: D6.C, R6.2
unnamed: D5.C, R17.2
unnamed: D1.6 (GA), U5.C1 (LED5)
unnamed: D1.4 (RA), U5.E1 (LED9)
unnamed: D2.2 (BA), U5.B2 (LED4)
unnamed: D4.C, R23.2
unnamed: D0.C, R20.2
unnamed: C53.1, U5.B5 (C1+)
unnamed: D2.6 (GA), U5.B1 (LED3)
unnamed: D2.4 (RA), U5.D2 (LED8)
unnamed: D3.2 (BA), U5.A2 (LED2)
unnamed: C54.1, U5.A5 (C2+)
unnamed: D3.6 (GA), U5.A1 (LED1)
unnamed: C54.2, U5.A4 (C2-)
unnamed: D3.4 (RA), U5.D1 (LED7)
VCC: D0.A, D4.A, D5.A, D6.A; also elsewhere on the board
VUNREG: C50.1, U5.C5 (VBAT); also elsewhere on the board

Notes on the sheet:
green
orange
red

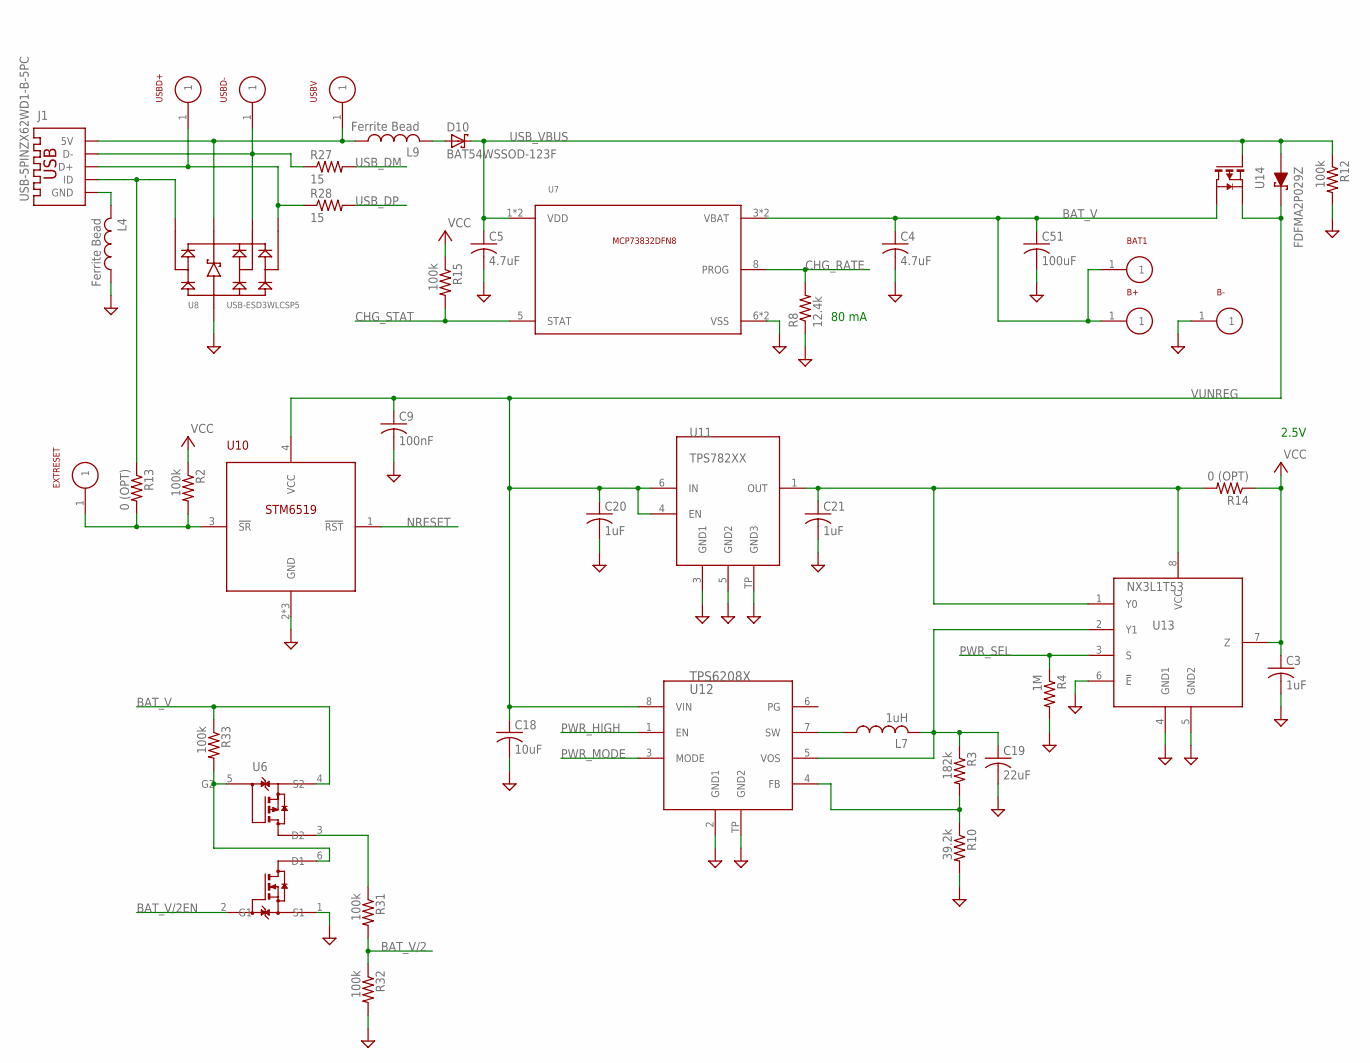
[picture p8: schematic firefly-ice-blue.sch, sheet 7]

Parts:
B+: TARGET-PINWP-28AWG; WP-28AWG
B-: TARGET-PINWP-28AWG; WP-28AWG
BAT1: TARGET-PIN; TARGET-PIN-1MM
C3, C20, C21: 1uF; C0201
C4, C5: 4.7uF; C0402
C9: 100nF; C0201
C18: 10uF; C0402
C19: 22uF; C0603
C51: 100uF; C1206
D10: BAT54WSSOD-123F; SOD-123F
EXTRESET: TARGET-PIN; TARGET-PIN-1MM
J1: USB-5PINZX62WD1-B-5PC; ZX62WD1-B-5PC
L4, L9: Ferrite Bead; L0201
L7: 1uH; L0805
R2, R12, R15, R31, R32, R33: 100k; R0201
R3: 182k; R0201
R4: 1M; R0201
R8: 12.4k; R0201
R10: 39.2k; R0201
R13, R14: 0 (OPT); R0201
R27, R28: 15; R0201
U6: MOSFET-N+PSOT963; SOT963
U7: MCP73832DFN8; DFN8
U8: USB-ESD3WLCSP5; WLCSP5
U10: STM6519; UDFN6
U11: TPS782XX; S-PWSON-N6
U12: TPS6208X; S-PWSON-N8
U13: NX3L1T53; SOT902-2
U14: FDFMA2P029Z; MO-229
USBD+: TARGET-PIN; TARGET-PIN-1MM
USBD-: TARGET-PIN; TARGET-PIN-1MM
USBV: TARGET-PIN; TARGET-PIN-1MM

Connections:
BAT_V: B+.1, BAT1.1, C4.1, C51.1, R33.1, U6.4 (S2), U7.3 (VBAT), U7.4 (VBAT), U14.3 (D)
BAT_V/2: R31.2, R32.1; also elsewhere on the board
BAT_V/2EN: U6.2 (G1); also elsewhere on the board
CHG_RATE: R8.2, U7.8 (PROG); also elsewhere on the board
CHG_STAT: R15.2, U7.5 (STAT); also elsewhere on the board
GND: B-.1, C3.2, C4.2, C5.2, C9.2, C18.2, C19.2, C20.2, C21.2, C51.2, L4.1, R4.2, R8.1, R10.2, R12.2, R32.2, U6.1 (S1), U7.6 (VSS), U7.PGND (VSS), U8.B1 (GND), U10.2 (GND), U10.5 (GND), U10.6 (GND), U11.3 (GND1), U11.5 (GND2), U11.TP (GND3), U12.2 (GND1), U12.TP (GND2), U13.4 (GND1), U13.5 (GND2), U13.6 (!E); also elsewhere on the board
unnamed: J1.5 (GND), L4.2
unnamed: R3.2, R10.1, U12.4 (FB)
unnamed: J1.4 (ID), R13.1, U8.C2 (IO1)
unnamed: EXTRESET.1, R2.2, R13.2, U10.3 (!SR)
unnamed: J1.3 (D+), R28.1, U8.C1 (IO3), USBD+.1
unnamed: L7.1, U12.7 (SW)
unnamed: C21.1, R14.2, U11.1 (OUT), U13.1 (Y0), U13.8 (VCC)
unnamed: D10.A, L9.2
unnamed: J1.2 (D-), R27.1, U8.A1 (IO2), USBD-.1
unnamed: J1.1 (5V), L9.1, U8.A2 (VBUS), USBV.1
unnamed: C19.1, L7.2, R3.1, U12.5 (VOS), U13.2 (Y1)
unnamed: R33.2, U6.5 (G2), U6.6 (D1)
unnamed: R31.1, U6.3 (D2)
NRESET: U10.1 (!RST); also elsewhere on the board
PWR_HIGH: U12.1 (EN); also elsewhere on the board
PWR_MODE: U12.3 (MODE); also elsewhere on the board
PWR_SEL: R4.1, U13.3 (S); also elsewhere on the board
USB_DM: R27.2; also elsewhere on the board
USB_DP: R28.2; also elsewhere on the board
USB_VBUS: C5.1, D10.C, R12.1, U7.1 (VDD), U7.2 (VDD), U14.1 (A), U14.5 (G); also elsewhere on the board
VCC: C3.1, R2.1, R14.1, R15.1, U13.7 (Z); also elsewhere on the board
VUNREG: C9.1, C18.1, C20.1, U10.4 (VCC), U11.4 (EN), U11.6 (IN), U12.8 (VIN), U14.4 (S), U14.6 (C); also elsewhere on the board

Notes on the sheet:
2.5V
80 mA

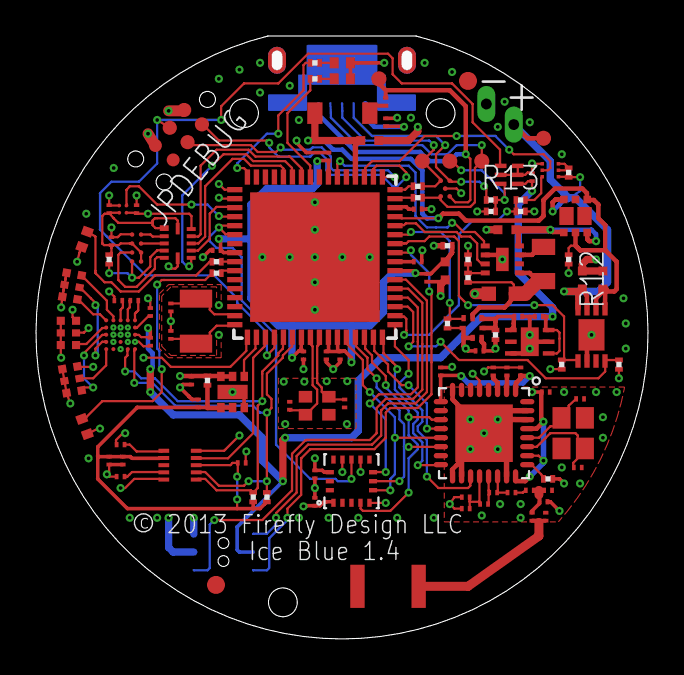
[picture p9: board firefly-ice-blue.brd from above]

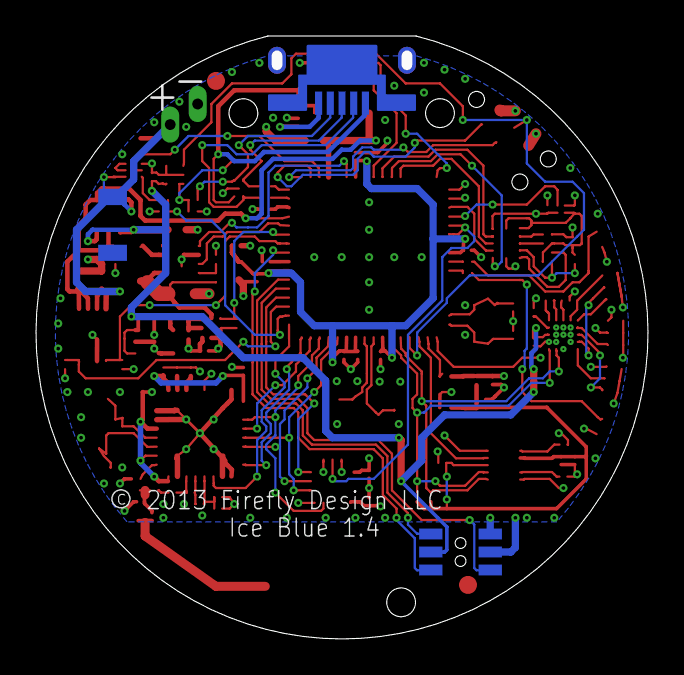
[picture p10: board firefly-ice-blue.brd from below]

Board: 4 copper layers, 34.0 x 33.5 mm, 122 parts (3 on the bottom side), 100 nets.

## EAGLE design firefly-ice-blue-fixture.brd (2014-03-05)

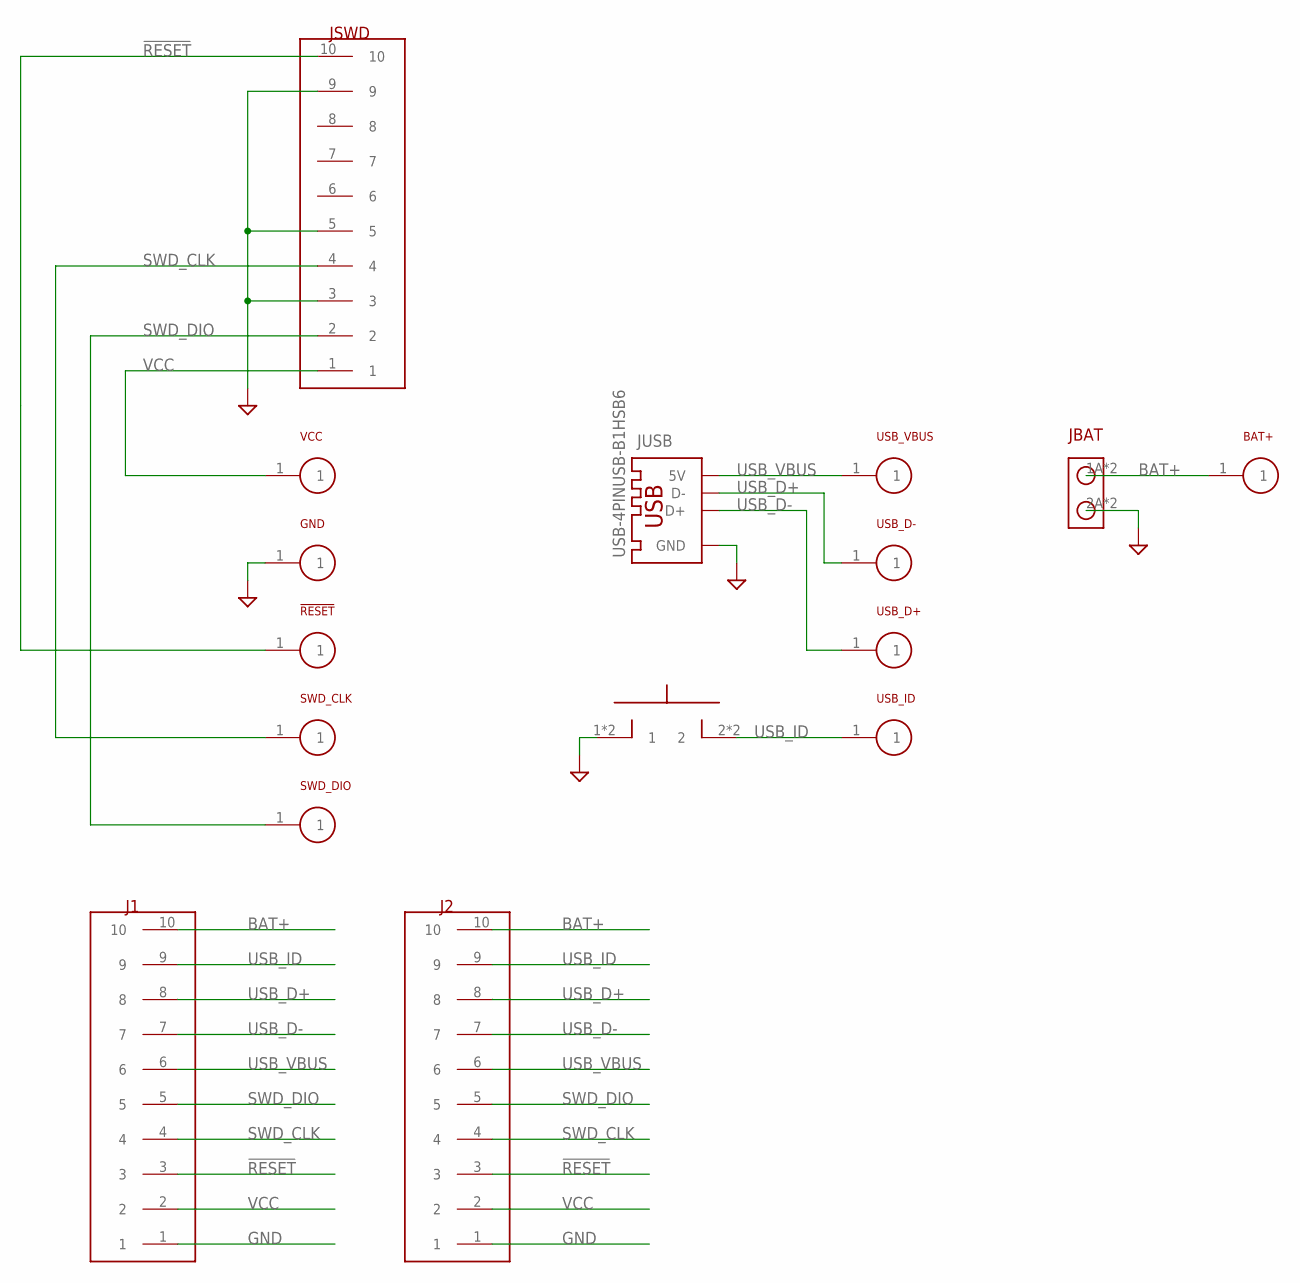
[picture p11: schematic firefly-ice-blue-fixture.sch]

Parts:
!RESET: TARGET-PINPROBE-0985; PROBE-0985
BAT+: TARGET-PINPROBE-0985; PROBE-0985
GND: TARGET-PINPROBE-0985; PROBE-0985
J1, J2: CON-10; CON-HEADER-10
JBAT: CON-220020303-D021B01LF; 20020303-D021B01LF
JSWD: CON-10SWD; SWD-10
JUSB: USB-4PINUSB-B1HSB6; USB-B1HSB6
SRES: SPST-NOKS-01Q-01; KS-01Q-01
SWD_CLK: TARGET-PINPROBE-0985; PROBE-0985
SWD_DIO: TARGET-PINPROBE-0985; PROBE-0985
USB_D+: TARGET-PINPROBE-0985; PROBE-0985
USB_D-: TARGET-PINPROBE-0985; PROBE-0985
USB_ID: TARGET-PINPROBE-0985; PROBE-0985
USB_VBUS: TARGET-PINPROBE-0985; PROBE-0985
VCC: TARGET-PINPROBE-0985; PROBE-0985

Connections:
!RESET: !RESET.1, J1.3, J2.3, JSWD.10
BAT+: BAT+.1, J1.10, J2.10, JBAT.1A (1), JBAT.1B (1)
GND: GND.1, J1.1, J2.1, JBAT.2A (2), JBAT.2B (2), JSWD.3, JSWD.5, JSWD.9, JUSB.4 (GND), SRES.1, SRES.3 (1)
SWD_CLK: J1.4, J2.4, JSWD.4, SWD_CLK.1
SWD_DIO: J1.5, J2.5, JSWD.2, SWD_DIO.1
USB_D+: J1.8, J2.8, JUSB.2 (D-), USB_D-.1
USB_D-: J1.7, J2.7, JUSB.3 (D+), USB_D+.1
USB_ID: J1.9, J2.9, SRES.2, SRES.4 (2), USB_ID.1
USB_VBUS: J1.6, J2.6, JUSB.1 (5V), USB_VBUS.1
VCC: J1.2, J2.2, JSWD.1, VCC.1

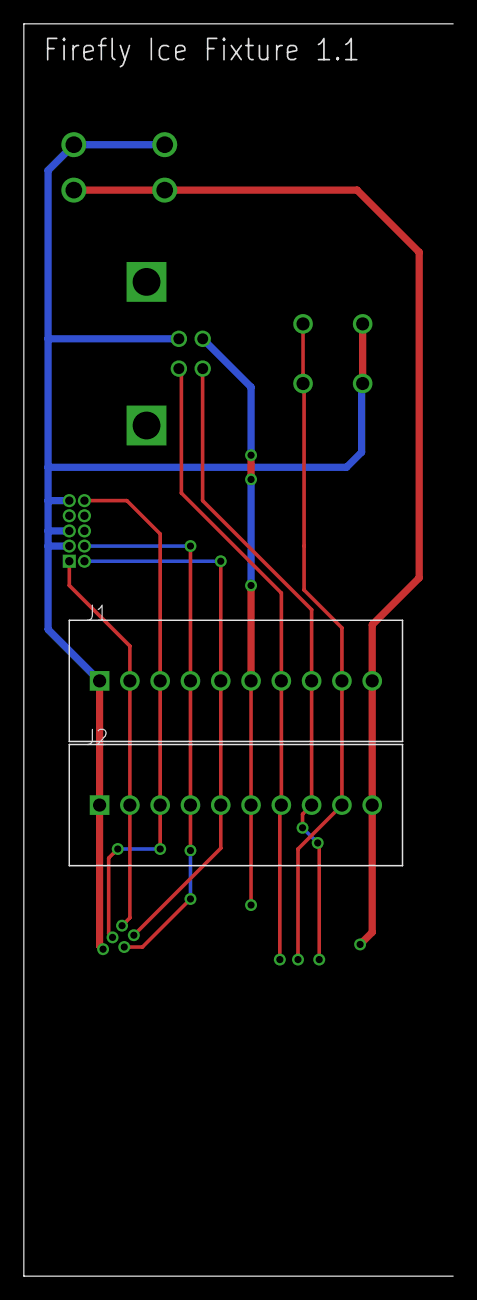
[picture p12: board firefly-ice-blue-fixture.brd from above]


Board: 2 copper layers, 36.0 x 105.0 mm, 16 parts (4 on the bottom side), 10 nets.

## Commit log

2013-03-22 initial version
    [firefly-ice.brd, firefly-ice.sch]
2013-05-09 add pdf version of schematic
2013-06-01 second version of firefly ice: blue
    [firefly-ice-blue.brd, firefly-ice-blue.sch]
2013-06-04 fix reversed source/drain on p-channel mosfet of voltage sensing circuit
    [firefly-ice-blue.brd, firefly-ice-blue.sch]
2013-06-08 add schematic, bom, and assembly diagrams (derived from schematic and layout)
    [firefly-ice-blue.brd, firefly-ice-blue.xls]
2013-07-13 switch to splashproof USB connector; fix voltage translator connections (swap A and B sides); DFM improvements
    [firefly-ice-blue.brd, firefly-ice-blue.sch, firefly-ice-blue.xls]
2013-07-29 add more part info for pricing
    [firefly-ice-blue.brd, firefly-ice-blue.sch]
2013-09-03 fix power/ground short in USB connector mounting posts; fix MOSI/MISO to memory and add chip select pullup
    [firefly-ice-blue.brd, firefly-ice-blue.sch]
2013-09-10 copy document layers so they can be used for silk names in panelized board
    [firefly-ice-blue.brd, firefly-ice-blue.sch, firefly-ice-blue.xls]
2014-01-06 add test fixture board
    [firefly-ice-blue-fixture.brd, firefly-ice-blue-fixture.sch, firefly-ice-blue.brd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]
2014-02-05 increase size of test probe holes
    [firefly-ice-blue-fixture.brd, firefly-ice-blue-fixture.sch]
2014-02-05 add new derived files
    [firefly-ice-blue-bom.xls, firefly-ice-blue.xls]
2014-03-05 update some ordering codes
    [firefly-ice-blue.brd, firefly-ice-blue.sch]
2014-03-05 move silk to component side of fixture PCB; remove old firefly ice
    [firefly-ice-blue-fixture.brd, firefly-ice.brd, firefly-ice.sch]
2014-04-27 raise voltage to 2.5V; make external usb id reset optional
    [firefly-ice-blue.brd, firefly-ice-blue.sch]
2014-05-14 add accelerometer interrupt to pin 5 (since pin 4 can't be shared due to radio use)
    [firefly-ice-blue.brd, firefly-ice-blue.sch]
2015-08-19 switch connector
    [firefly-ice-blue.brd, firefly-ice-blue.sch]
2016-05-04 add instrument tray
    [firefly-instrument-tray.brd, firefly-instrument-tray.sch]
2016-05-09 instrument tray ready to fab first version
    [firefly-instrument-tray.brd, firefly-instrument-tray.sch]
2016-06-01 rev 0.2 of instrument board
    [firefly-instrument-tray.brd, firefly-instrument-tray.sch]
2016-06-24 fix ordering codes on instrument board
    [firefly-instrument-tray.brd, firefly-instrument-tray.sch]
2016-08-23 Firefly Instrument Tray 0.3 (out for fab)
    [firefly-instrument-tray.brd, firefly-instrument-tray.sch]
2016-10-04 Rev 0.4 instrument board - ready for production
    [firefly-instrument-tray.brd, firefly-instrument-tray.sch]
2016-10-19 fix SPI memory ordering code
    [firefly-instrument-tray.brd, firefly-instrument-tray.sch]
2017-04-12 add battery simulator voltage to A/D; separate motor minus from ground; remove J2; bump to version 0.5
    [firefly-instrument-tray.brd, firefly-instrument-tray.sch]
2017-04-13 revision 0.5 ready for production
    [firefly-instrument-tray.brd, firefly-instrument-tray.sch]

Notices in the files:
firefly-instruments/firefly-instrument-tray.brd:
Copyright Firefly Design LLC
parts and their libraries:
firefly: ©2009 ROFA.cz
